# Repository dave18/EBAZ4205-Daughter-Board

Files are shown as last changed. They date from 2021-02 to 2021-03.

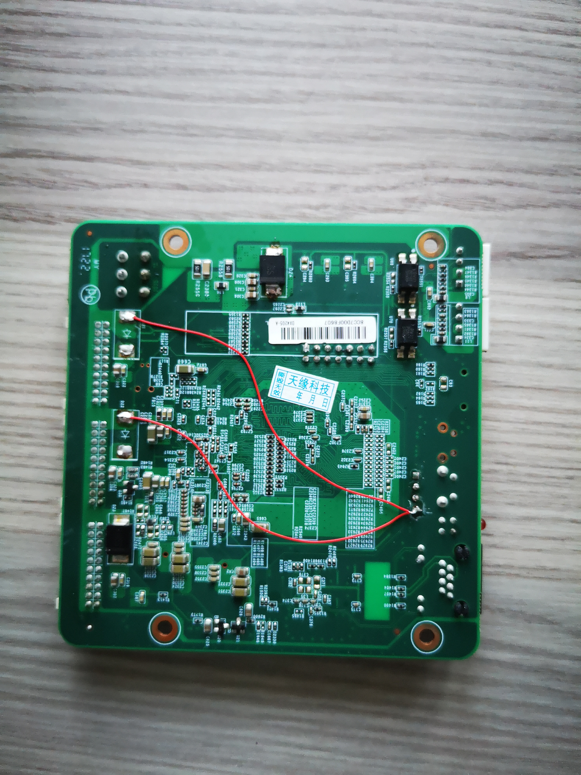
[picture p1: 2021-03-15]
EBAZ4205_Board_Bottom.jpg

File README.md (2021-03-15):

# EBAZ4205-Daughter-Board
Simple daughter board for EBAZ4205 FPGA with VGA, PS2 and standard 2.54 header

Daughter board to add VGA, SD Card Breakout and PS2 {keyboard, not playstation ;-)}  functionality to the EBAZ54205 miner board.

Also brings out IO pins to standard 2.54 header for easier interfacing.  SD Card and PS2 signal also available on pin header.

All through hole for easy assembly

Notes:

PS2 needs 5v so a 12v needs to be taken to the 12v header +connector which feeds the 5v regulator, or a separate 5v source taken directly to the 5v header.
I've adapted my EBAZ4205 board to provide 3.3V out on the VCC pins on Data 1 and Data 2.  To do this I removed the diodes at D21 and D23 and run a wire from the 3.3V VCC pin of the serial interface at J7.  There are diodes on the daughter board to avoid accidental back powering of the EBAZ4205 board.  Without this mod VGA still works but an alternative way of powering the 3.3v circuit for the SD Card and PS2 3.3v side is needed.

Design could be improved by bringing the 2mm headers neader the edge of the board but they still connect fine as they are

The 2 individual 16 pin 2.54 headers could be changed to a proper 2 x 16 pin header (they are currently spaced slightly too far apart for a 2x16 IDC connector)

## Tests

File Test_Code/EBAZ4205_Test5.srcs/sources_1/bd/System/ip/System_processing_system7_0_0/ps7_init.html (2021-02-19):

- Zynq PS Register Summary Viewer

Zynq PS7 Summary Report

User Configurations

MIO Configurations

CLK Configurations

DDR Configurations

SMC Configurations

Select Version:

Zynq Register View

MIO Registers

PLL Registers

Clock Registers

DDR Registers

Peripherals Registers

This design is targeted for xc7z010 board (part number: xc7z010clg400-1)

# Zynq Design Summary

Device | xc7z010
SpeedGrade | -1
Part | xc7z010clg400-1
Description | Zynq PS Configuration Report with register details
Vendor | Xilinx

## MIO Table View

MIO Pin | Peripheral | Signal | IO Type | Speed | Pullup | Direction
MIO 0 | NAND Flash | cs | LVCMOS 3.3V | slow | enabled | out
MIO 1
MIO 2 | NAND Flash | ale | LVCMOS 3.3V | slow | disabled | out
MIO 3 | NAND Flash | we_b | LVCMOS 3.3V | slow | disabled | out
MIO 4 | NAND Flash | data[2] | LVCMOS 3.3V | slow | disabled | inout
MIO 5 | NAND Flash | data[0] | LVCMOS 3.3V | slow | disabled | inout
MIO 6 | NAND Flash | data[1] | LVCMOS 3.3V | slow | disabled | inout
MIO 7 | NAND Flash | cle | LVCMOS 3.3V | slow | disabled | out
MIO 8 | NAND Flash | re_b | LVCMOS 3.3V | slow | disabled | out
MIO 9 | NAND Flash | data[4] | LVCMOS 3.3V | slow | enabled | inout
MIO 10 | NAND Flash | data[5] | LVCMOS 3.3V | slow | enabled | inout
MIO 11 | NAND Flash | data[6] | LVCMOS 3.3V | slow | enabled | inout
MIO 12 | NAND Flash | data[7] | LVCMOS 3.3V | slow | enabled | inout
MIO 13 | NAND Flash | data[3] | LVCMOS 3.3V | slow | enabled | inout
MIO 14 | NAND Flash | busy | LVCMOS 3.3V | slow | enabled | in
MIO 15
MIO 16
MIO 17
MIO 18
MIO 19
MIO 20
MIO 21
MIO 22
MIO 23
MIO 24 | UART 1 | tx | LVCMOS 3.3V | slow | enabled | out
MIO 25 | UART 1 | rx | LVCMOS 3.3V | slow | enabled | in
MIO 26
MIO 27
MIO 28
MIO 29
MIO 30
MIO 31
MIO 32
MIO 33
MIO 34
MIO 35
MIO 36
MIO 37
MIO 38
MIO 39
MIO 40
MIO 41
MIO 42
MIO 43
MIO 44
MIO 45
MIO 46
MIO 47
MIO 48
MIO 49
MIO 50
MIO 51
MIO 52
MIO 53

## DDR Memory information

Parameter name | Value | Description
Enable DDR | 1 | Enable DDR Controller of Zynq PS
Memory Part | MT41K128M16 JT-125
DRAM bus width | 16 Bit | Select the desired data width. Refer to the Thechnical Reference Manual(TRM) for a detailed list of supported DDR data widths
ECC | Disabled | ECC is supported only for data width of 16-bit
BURST Length (lppdr only) | 8 | Select the burst Length. It refers to the amount of data read/written after a read/write command is presented to the controller
Internal Vref | 0
Operating Frequency (MHz) | 533.333333 | Chose the clock period for the desired frequency. The allowed freq range (200 - 667 MHz) is a function of FPGA part and FPGA speed grade
HIGH temperature | Normal (0-85) | Select the operating temparature
DRAM IC bus width | 16 Bits | Provide the width of the DRAM chip
DRAM Device Capacity | 2048 MBits
Speed Bin | DDR3_1066F | Provide the Speed Bin
BANK Address Count | 3 | Defines the bank to which an active an ACTIVE, READ, WRITE, or Precharge Command is being applied
ROW Address Count | 14 | Provide the Row address for ACTIVE commands
COLUMN Address Count | 10 | Provide the Row address for READ/WRITE commands
CAS Latency | 7 | Select the Column Access Strobe (CAS) Latency. It refers to the amount of time it takes for data to appear on the pins of the memory module
CAS Write Latency | 6 | Select the CAS Write Latency
RAS to CAS Delay | 7 | Provide the row address to column address delay time. tRCD is t he time required between the memory controller asserting a row address strobe (RAS), and then asserting the column address strobe (CAS)
RECHARGE Time | 7 | Precharge Time (tRP) is the number of clock cycles needed o terminate acces s to an open row of memory, and open access to the next row
tRC (ns ) | 48.75 | Provide the Row cycle time tRC (ns)
tRASmin ( ns ) | 35.0 | tRASmin (ns) is the minimum number of clock cycles required between an Active command and issuing the Precharge command
tFAW | 40.0 | It restricts the number of activates that can be done within a certain window of time
ADDITIVE Latency | 0 | Provide the Additive Latency (ns). Increases the efficiency of the command and data bus for sustainable bandwidths
Write levelling | 1
Read gate | 1
Read gate | 1
DQS to Clock delay [0] (ns) | 0.0 | The daly difference of each DQS path delay subtracted from the clock path delay
DQS to Clock delay [1] (ns) | 0.0 | The daly difference of each DQS path delay subtracted from the clock path delay
DQS to Clock delay [2] (ns) | 0.0 | The daly difference of each DQS path delay subtracted from the clock path delay
DQS to Clock delay [3] (ns) | 0.0 | The daly difference of each DQS path delay subtracted from the clock path delay
Board delay [0] (ns) | 0.25 | The average of the data midpoint delay, of the data delays associated with a byte lane (DDR_DQ, DDR_DM) averaged with the midpoint of the cloc kdelays (DDR_CK, DR_CK_N)
Board delay [1] (ns) | 0.25 | The average of the data midpoint delay, of the data delays associated with a byte lane (DDR_DQ, DDR_DM) averaged with the midpoint of the cloc kdelays (DDR_CK, DR_CK_N)
Board delay [2] (ns) | 0.25 | The average of the data midpoint delay, of the data delays associated with a byte lane (DDR_DQ, DDR_DM) averaged with the midpoint of the cloc kdelays (DDR_CK, DR_CK_N)
Board delay [3] (ns) | 0.25 | The average of the data midpoint delay, of the data delays associated with a byte lane (DDR_DQ, DDR_DM) averaged with the midpoint of the cloc kdelays (DDR_CK, DR_CK_N)

## PS Clocks information

## PS Reference Clock : 33.333333

Peripheral | PLL source | Frequency (MHz)
CPU 6x Freq (MHz) | ARM PLL | 666.666687
SMC Freq (MHz) | IO PLL | 100.000000
UART Freq (MHz) | IO PLL | 100.000000
FPGA0 Freq (MHz) | ARM PLL | 102.564102
FPGA1 Freq (MHz) | ARM PLL | 25.157234
FPGA2 Freq (MHz) | IO PLL | 10.000000
FPGA3 Freq (MHz) | IO PLL | 10.000000

## ps7_pll_init_data_3_0

Register Name | Address | Width | Type | Reset Value | Description
SLCR_UNLOCK | 0XF8000008 | 32 | WO | 0x000000 | SLCR Write Protection Unlock
ARM_PLL_CFG | 0XF8000110 | 32 | RW | 0x000000 | ARM PLL Configuration
ARM_PLL_CTRL | 0XF8000100 | 32 | RW | 0x000000 | ARM PLL Control
ARM_PLL_CTRL | 0XF8000100 | 32 | RW | 0x000000 | ARM PLL Control
ARM_PLL_CTRL | 0XF8000100 | 32 | RW | 0x000000 | ARM PLL Control
ARM_PLL_CTRL | 0XF8000100 | 32 | RW | 0x000000 | ARM PLL Control
ARM_PLL_CTRL | 0XF8000100 | 32 | RW | 0x000000 | ARM PLL Control
ARM_CLK_CTRL | 0XF8000120 | 32 | RW | 0x000000 | CPU Clock Control
DDR_PLL_CFG | 0XF8000114 | 32 | RW | 0x000000 | DDR PLL Configuration
DDR_PLL_CTRL | 0XF8000104 | 32 | RW | 0x000000 | DDR PLL Control
DDR_PLL_CTRL | 0XF8000104 | 32 | RW | 0x000000 | DDR PLL Control
DDR_PLL_CTRL | 0XF8000104 | 32 | RW | 0x000000 | DDR PLL Control
DDR_PLL_CTRL | 0XF8000104 | 32 | RW | 0x000000 | DDR PLL Control
DDR_PLL_CTRL | 0XF8000104 | 32 | RW | 0x000000 | DDR PLL Control
DDR_CLK_CTRL | 0XF8000124 | 32 | RW | 0x000000 | DDR Clock Control
IO_PLL_CFG | 0XF8000118 | 32 | RW | 0x000000 | IO PLL Configuration
IO_PLL_CTRL | 0XF8000108 | 32 | RW | 0x000000 | IO PLL Control
IO_PLL_CTRL | 0XF8000108 | 32 | RW | 0x000000 | IO PLL Control
IO_PLL_CTRL | 0XF8000108 | 32 | RW | 0x000000 | IO PLL Control
IO_PLL_CTRL | 0XF8000108 | 32 | RW | 0x000000 | IO PLL Control
IO_PLL_CTRL | 0XF8000108 | 32 | RW | 0x000000 | IO PLL Control
SLCR_LOCK | 0XF8000004 | 32 | WO | 0x000000 | SLCR Write Protection Lock

## ps7_pll_init_data_3_0

Register Name | Address | Width | Type | Reset Value | Description

# SLCR SETTINGS

## Register ( slcr )SLCR_UNLOCK

Register Name | Address | Width | Type | Reset Value | Description
SLCR_UNLOCK | 0XF8000008 | 32 | rw | 0x00000000 | --

Field Name | Bits | Mask | Value | Shifted Value | Description
UNLOCK_KEY | 15:0 | ffff | df0d | df0d | Write the unlock key, 0xDF0D, to enable writes to the slcr registers. All slcr registers, 0xF800_0000 to 0xF800_0B74, are writeable until locked using the SLCR_LOCK register. A read of this register returns zero.
SLCR_UNLOCK@0XF8000008 | 31:0 | ffff | | df0d | SLCR Write Protection Unlock

# PLL SLCR REGISTERS

# ARM PLL INIT

## Register ( slcr )ARM_PLL_CFG

Register Name | Address | Width | Type | Reset Value | Description
ARM_PLL_CFG | 0XF8000110 | 32 | rw | 0x00000000 | --

Field Name | Bits | Mask | Value | Shifted Value | Description
PLL_RES | 7:4 | f0 | 2 | 20 | Drive the PLL_RES[3:0] input of the PLL to set the PLL loop filter resistor control
PLL_CP | 11:8 | f00 | 2 | 200 | Drive the PLL_CP[3:0] input of the PLL to set the PLL charge pump control
LOCK_CNT | 21:12 | 3ff000 | fa | fa000 | Drive the LOCK_CNT[9:0] input of the PLL to set the number of clock cycles the PLL needs to have clkref and clkfb aligned with a certain window before syaing locked.
ARM_PLL_CFG@0XF8000110 | 31:0 | 3ffff0 | | fa220 | ARM PLL Configuration

# UPDATE FB_DIV

## Register ( slcr )ARM_PLL_CTRL

Register Name | Address | Width | Type | Reset Value | Description
ARM_PLL_CTRL | 0XF8000100 | 32 | rw | 0x00000000 | --

Field Name | Bits | Mask | Value | Shifted Value | Description
PLL_FDIV | 18:12 | 7f000 | 28 | 28000 | Provide the feedback divisor for the PLL. Note: Before changing this value, the PLL must first be bypassed and then put into reset mode. Refer to the Zynq-7000 TRM, UG585, Clocks chapter for CP/RES/CNT values for the PLL.
ARM_PLL_CTRL@0XF8000100 | 31:0 | 7f000 | | 28000 | ARM PLL Control

# BY PASS PLL

## Register ( slcr )ARM_PLL_CTRL

Register Name | Address | Width | Type | Reset Value | Description
ARM_PLL_CTRL | 0XF8000100 | 32 | rw | 0x00000000 | --

Field Name | Bits | Mask | Value | Shifted Value | Description
PLL_BYPASS_FORCE | 4:4 | 10 | 1 | 10 | ARM PLL Bypass override control: PLL_BYPASS_QUAL = 0: 0: enabled, not bypassed. 1: bypassed. PLL_BYPASS_QUAL = 1 (QUAL bit default value): 0: PLL mode is set based on pin strap setting. 1: PLL bypassed regardless of the pin strapping.
ARM_PLL_CTRL@0XF8000100 | 31:0 | 10 | | 10 | ARM PLL Control

# ASSERT RESET

## Register ( slcr )ARM_PLL_CTRL

Register Name | Address | Width | Type | Reset Value | Description
ARM_PLL_CTRL | 0XF8000100 | 32 | rw | 0x00000000 | --

Field Name | Bits | Mask | Value | Shifted Value | Description
PLL_RESET | 0:0 | 1 | 1 | 1 | PLL reset control: 0: de-assert (PLL operating) 1: assert (PLL held in reset)
ARM_PLL_CTRL@0XF8000100 | 31:0 | 1 | | 1 | ARM PLL Control

# DEASSERT RESET

## Register ( slcr )ARM_PLL_CTRL

Register Name | Address | Width | Type | Reset Value | Description
ARM_PLL_CTRL | 0XF8000100 | 32 | rw | 0x00000000 | --

Field Name | Bits | Mask | Value | Shifted Value | Description
PLL_RESET | 0:0 | 1 | 0 | 0 | PLL reset control: 0: de-assert (PLL operating) 1: assert (PLL held in reset)
ARM_PLL_CTRL@0XF8000100 | 31:0 | 1 | | 0 | ARM PLL Control

# CHECK PLL STATUS

## Register ( slcr )PLL_STATUS

Register Name | Address | Width | Type | Reset Value | Description
PLL_STATUS | 0XF800010C | 32 | rw | 0x00000000 | --

Field Name | Bits | Mask | Value | Shifted Value | Description
ARM_PLL_LOCK | 0:0 | 1 | 1 | 1 | ARM PLL lock status: 0: not locked, 1: locked
PLL_STATUS@0XF800010C | 31:0 | 1 | | 1 | tobe

# REMOVE PLL BY PASS

## Register ( slcr )ARM_PLL_CTRL

Register Name | Address | Width | Type | Reset Value | Description
ARM_PLL_CTRL | 0XF8000100 | 32 | rw | 0x00000000 | --

Field Name | Bits | Mask | Value | Shifted Value | Description
PLL_BYPASS_FORCE | 4:4 | 10 | 0 | 0 | ARM PLL Bypass override control: PLL_BYPASS_QUAL = 0: 0: enabled, not bypassed. 1: bypassed. PLL_BYPASS_QUAL = 1 (QUAL bit default value): 0: PLL mode is set based on pin strap setting. 1: PLL bypassed regardless of the pin strapping.
ARM_PLL_CTRL@0XF8000100 | 31:0 | 10 | | 0 | ARM PLL Control

## Register ( slcr )ARM_CLK_CTRL

Register Name | Address | Width | Type | Reset Value | Description
ARM_CLK_CTRL | 0XF8000120 | 32 | rw | 0x00000000 | --

Field Name | Bits | Mask | Value | Shifted Value | Description
SRCSEL | 5:4 | 30 | 0 | 0 | Select the source used to generate the CPU clock: 0x: ARM PLL 10: DDR PLL 11: IO PLL This field is reset by POR only.
DIVISOR | 13:8 | 3f00 | 2 | 200 | Frequency divisor for the CPU clock source.
CPU_6OR4XCLKACT | 24:24 | 1000000 | 1 | 1000000 | CPU_6x4x Clock control: 0: disable, 1: enable
CPU_3OR2XCLKACT | 25:25 | 2000000 | 1 | 2000000 | CPU_3x2x Clock control: 0: disable, 1: enable
CPU_2XCLKACT | 26:26 | 4000000 | 1 | 4000000 | CPU_2x Clock control: 0: disable, 1: enable
CPU_1XCLKACT | 27:27 | 8000000 | 1 | 8000000 | CPU_1x Clock control: 0: disable, 1: enable
CPU_PERI_CLKACT | 28:28 | 10000000 | 1 | 10000000 | Clock active: 0: Clock is disabled 1: Clock is enabled
ARM_CLK_CTRL@0XF8000120 | 31:0 | 1f003f30 | | 1f000200 | CPU Clock Control

# DDR PLL INIT

## Register ( slcr )DDR_PLL_CFG

Register Name | Address | Width | Type | Reset Value | Description
DDR_PLL_CFG | 0XF8000114 | 32 | rw | 0x00000000 | --

Field Name | Bits | Mask | Value | Shifted Value | Description
PLL_RES | 7:4 | f0 | 2 | 20 | Drive the PLL_RES[3:0] input of the PLL to set the PLL loop filter resistor control.
PLL_CP | 11:8 | f00 | 2 | 200 | Drive the PLL_CP[3:0] input of the PLL to set the PLL charge pump control.
LOCK_CNT | 21:12 | 3ff000 | 12c | 12c000 | Drive the LOCK_CNT[9:0] input of the PLL to set the number of clock cycles the PLL needs to have clkref and clkfb aligned with a certain window before staying locked.
DDR_PLL_CFG@0XF8000114 | 31:0 | 3ffff0 | | 12c220 | DDR PLL Configuration

# UPDATE FB_DIV

## Register ( slcr )DDR_PLL_CTRL

Register Name | Address | Width | Type | Reset Value | Description
DDR_PLL_CTRL | 0XF8000104 | 32 | rw | 0x00000000 | --

Field Name | Bits | Mask | Value | Shifted Value | Description
PLL_FDIV | 18:12 | 7f000 | 20 | 20000 | Provide the feedback divisor for the PLL. Note: Before changing this value, the PLL must first be bypassed and then put into reset mode. Refer to the Zynq-7000 TRM, UG585, Clocks chapter for CP/RES/CNT values for the PLL.
DDR_PLL_CTRL@0XF8000104 | 31:0 | 7f000 | | 20000 | DDR PLL Control

# BY PASS PLL

## Register ( slcr )DDR_PLL_CTRL

Register Name | Address | Width | Type | Reset Value | Description
DDR_PLL_CTRL | 0XF8000104 | 32 | rw | 0x00000000 | --

Field Name | Bits | Mask | Value | Shifted Value | Description
PLL_BYPASS_FORCE | 4:4 | 10 | 1 | 10 | DDR PLL Bypass override control: PLL_BYPASS_QUAL = 0 0: enabled, not bypassed. 1: bypassed. PLL_BYPASS_QUAL = 1 (QUAL bit default value) 0: PLL mode is set based on pin strap setting. 1: PLL bypass is enabled regardless of the pin strapping.
DDR_PLL_CTRL@0XF8000104 | 31:0 | 10 | | 10 | DDR PLL Control

# ASSERT RESET

## Register ( slcr )DDR_PLL_CTRL

Register Name | Address | Width | Type | Reset Value | Description
DDR_PLL_CTRL | 0XF8000104 | 32 | rw | 0x00000000 | --

Field Name | Bits | Mask | Value | Shifted Value | Description
PLL_RESET | 0:0 | 1 | 1 | 1 | PLL reset control: 0: de-assert (PLL operating) 1: assert (PLL held in reset)
DDR_PLL_CTRL@0XF8000104 | 31:0 | 1 | | 1 | DDR PLL Control

# DEASSERT RESET

## Register ( slcr )DDR_PLL_CTRL

Register Name | Address | Width | Type | Reset Value | Description
DDR_PLL_CTRL | 0XF8000104 | 32 | rw | 0x00000000 | --

Field Name | Bits | Mask | Value | Shifted Value | Description
PLL_RESET | 0:0 | 1 | 0 | 0 | PLL reset control: 0: de-assert (PLL operating) 1: assert (PLL held in reset)
DDR_PLL_CTRL@0XF8000104 | 31:0 | 1 | | 0 | DDR PLL Control

# CHECK PLL STATUS

## Register ( slcr )PLL_STATUS

Register Name | Address | Width | Type | Reset Value | Description
PLL_STATUS | 0XF800010C | 32 | rw | 0x00000000 | --

Field Name | Bits | Mask | Value | Shifted Value | Description
DDR_PLL_LOCK | 1:1 | 2 | 1 | 2 | DDR PLL lock status: 0: not locked, 1: locked
PLL_STATUS@0XF800010C | 31:0 | 2 | | 2 | tobe

# REMOVE PLL BY PASS

## Register ( slcr )DDR_PLL_CTRL

Register Name | Address | Width | Type | Reset Value | Description
DDR_PLL_CTRL | 0XF8000104 | 32 | rw | 0x00000000 | --

Field Name | Bits | Mask | Value | Shifted Value | Description
PLL_BYPASS_FORCE | 4:4 | 10 | 0 | 0 | DDR PLL Bypass override control: PLL_BYPASS_QUAL = 0 0: enabled, not bypassed. 1: bypassed. PLL_BYPASS_QUAL = 1 (QUAL bit default value) 0: PLL mode is set based on pin strap setting. 1: PLL bypass is enabled regardless of the pin strapping.
DDR_PLL_CTRL@0XF8000104 | 31:0 | 10 | | 0 | DDR PLL Control

## Register ( slcr )DDR_CLK_CTRL

Register Name | Address | Width | Type | Reset Value | Description
DDR_CLK_CTRL | 0XF8000124 | 32 | rw | 0x00000000 | --

Field Name | Bits | Mask | Value | Shifted Value | Description
DDR_3XCLKACT | 0:0 | 1 | 1 | 1 | DDR_3x Clock control: 0: disable, 1: enable
DDR_2XCLKACT | 1:1 | 2 | 1 | 2 | DDR_2x Clock control: 0: disable, 1: enable
DDR_3XCLK_DIVISOR | 25:20 | 3f00000 | 2 | 200000 | Frequency divisor for the ddr_3x clock
DDR_2XCLK_DIVISOR | 31:26 | fc000000 | 3 | c000000 | Frequency divisor for the ddr_2x clock
DDR_CLK_CTRL@0XF8000124 | 31:0 | fff00003 | | c200003 | DDR Clock Control

# IO PLL INIT

## Register ( slcr )IO_PLL_CFG

Register Name | Address | Width | Type | Reset Value | Description
IO_PLL_CFG | 0XF8000118 | 32 | rw | 0x00000000 | --

Field Name | Bits | Mask | Value | Shifted Value | Description
PLL_RES | 7:4 | f0 | 4 | 40 | Drive the PLL_RES[3:0] input of the PLL to set the PLL loop filter resistor control.
PLL_CP | 11:8 | f00 | 2 | 200 | Drive the PLL_CP[3:0] input of the PLL to set the PLL charge pump control.
LOCK_CNT | 21:12 | 3ff000 | fa | fa000 | Drive the LOCK_CNT[9:0] input of the PLL to set the number of clock cycles the PLL needs to have clkref and clkfb aligned with a certain window before staying locked.
IO_PLL_CFG@0XF8000118 | 31:0 | 3ffff0 | | fa240 | IO PLL Configuration

# UPDATE FB_DIV

## Register ( slcr )IO_PLL_CTRL

Register Name | Address | Width | Type | Reset Value | Description
IO_PLL_CTRL | 0XF8000108 | 32 | rw | 0x00000000 | --

Field Name | Bits | Mask | Value | Shifted Value | Description
PLL_FDIV | 18:12 | 7f000 | 30 | 30000 | Provide the feedback divisor for the PLL. Note: Before changing this value, the PLL must first be bypassed and then put into reset mode. Refer to the Zynq-7000 TRM, UG585, Clocks chapter for CP/RES/CNT values for programming the PLL.
IO_PLL_CTRL@0XF8000108 | 31:0 | 7f000 | | 30000 | IO PLL Control

# BY PASS PLL

## Register ( slcr )IO_PLL_CTRL

Register Name | Address | Width | Type | Reset Value | Description
IO_PLL_CTRL | 0XF8000108 | 32 | rw | 0x00000000 | --

Field Name | Bits | Mask | Value | Shifted Value | Description
PLL_BYPASS_FORCE | 4:4 | 10 | 1 | 10 | IO PLL Bypass override control: PLL_BYPASS_QUAL = 0 0: enabled, not bypassed. 1: bypassed. PLL_BYPASS_QUAL = 1 (QUAL bit default value) 0: PLL mode is set based on pin strap setting. 1: PLL bypass is enabled regardless of the pin strapping.
IO_PLL_CTRL@0XF8000108 | 31:0 | 10 | | 10 | IO PLL Control

# ASSERT RESET

## Register ( slcr )IO_PLL_CTRL

Register Name | Address | Width | Type | Reset Value | Description
IO_PLL_CTRL | 0XF8000108 | 32 | rw | 0x00000000 | --

Field Name | Bits | Mask | Value | Shifted Value | Description
PLL_RESET | 0:0 | 1 | 1 | 1 | PLL Reset control: 0: de-assert (PLL operating) 1: assert (PLL held in reset)
IO_PLL_CTRL@0XF8000108 | 31:0 | 1 | | 1 | IO PLL Control

# DEASSERT RESET

## Register ( slcr )IO_PLL_CTRL

Register Name | Address | Width | Type | Reset Value | Description
IO_PLL_CTRL | 0XF8000108 | 32 | rw | 0x00000000 | --

Field Name | Bits | Mask | Value | Shifted Value | Description
PLL_RESET | 0:0 | 1 | 0 | 0 | PLL Reset control: 0: de-assert (PLL operating) 1: assert (PLL held in reset)
IO_PLL_CTRL@0XF8000108 | 31:0 | 1 | | 0 | IO PLL Control

# CHECK PLL STATUS

## Register ( slcr )PLL_STATUS

Register Name | Address | Width | Type | Reset Value | Description
PLL_STATUS | 0XF800010C | 32 | rw | 0x00000000 | --

Field Name | Bits | Mask | Value | Shifted Value | Description
IO_PLL_LOCK | 2:2 | 4 | 1 | 4 | IO PLL lock status: 0: not locked, 1: locked
PLL_STATUS@0XF800010C | 31:0 | 4 | | 4 | tobe

# REMOVE PLL BY PASS

## Register ( slcr )IO_PLL_CTRL

Register Name | Address | Width | Type | Reset Value | Description
IO_PLL_CTRL | 0XF8000108 | 32 | rw | 0x00000000 | --

Field Name | Bits | Mask | Value | Shifted Value | Description
PLL_BYPASS_FORCE | 4:4 | 10 | 0 | 0 | IO PLL Bypass override control: PLL_BYPASS_QUAL = 0 0: enabled, not bypassed. 1: bypassed. PLL_BYPASS_QUAL = 1 (QUAL bit default value) 0: PLL mode is set based on pin strap setting. 1: PLL bypass is enabled regardless of the pin strapping.
IO_PLL_CTRL@0XF8000108 | 31:0 | 10 | | 0 | IO PLL Control

# LOCK IT BACK

## Register ( slcr )SLCR_LOCK

Register Name | Address | Width | Type | Reset Value | Description
SLCR_LOCK | 0XF8000004 | 32 | rw | 0x00000000 | --

Field Name | Bits | Mask | Value | Shifted Value | Description
LOCK_KEY | 15:0 | ffff | 767b | 767b | Write the lock key, 0x767B, to write protect the slcr registers: all slcr registers, 0xF800_0000 to 0xF800_0B74, are write protected until the unlock key is written to the SLCR_UNLOCK register. A read of this register returns zero.
SLCR_LOCK@0XF8000004 | 31:0 | ffff | | 767b | SLCR Write Protection Lock

## ps7_clock_init_data_3_0

Register Name | Address | Width | Type | Reset Value | Description
SLCR_UNLOCK | 0XF8000008 | 32 | WO | 0x000000 | SLCR Write Protection Unlock
DCI_CLK_CTRL | 0XF8000128 | 32 | RW | 0x000000 | DCI clock control
SMC_CLK_CTRL | 0XF8000148 | 32 | RW | 0x000000 | SMC Ref Clock Control
UART_CLK_CTRL | 0XF8000154 | 32 | RW | 0x000000 | UART Ref Clock Control
PCAP_CLK_CTRL | 0XF8000168 | 32 | RW | 0x000000 | PCAP Clock Control
FPGA0_CLK_CTRL | 0XF8000170 | 32 | RW | 0x000000 | PL Clock 0 Output control
FPGA1_CLK_CTRL | 0XF8000180 | 32 | RW | 0x000000 | PL Clock 1 Output control
CLK_621_TRUE | 0XF80001C4 | 32 | RW | 0x000000 | CPU Clock Ratio Mode select
APER_CLK_CTRL | 0XF800012C | 32 | RW | 0x000000 | AMBA Peripheral Clock Control
SLCR_LOCK | 0XF8000004 | 32 | WO | 0x000000 | SLCR Write Protection Lock

## ps7_clock_init_data_3_0

Register Name | Address | Width | Type | Reset Value | Description

# SLCR SETTINGS

## Register ( slcr )SLCR_UNLOCK

Register Name | Address | Width | Type | Reset Value | Description
SLCR_UNLOCK | 0XF8000008 | 32 | rw | 0x00000000 | --

Field Name | Bits | Mask | Value | Shifted Value | Description
UNLOCK_KEY | 15:0 | ffff | df0d | df0d | Write the unlock key, 0xDF0D, to enable writes to the slcr registers. All slcr registers, 0xF800_0000 to 0xF800_0B74, are writeable until locked using the SLCR_LOCK register. A read of this register returns zero.
SLCR_UNLOCK@0XF8000008 | 31:0 | ffff | | df0d | SLCR Write Protection Unlock

# CLOCK CONTROL SLCR REGISTERS

## Register ( slcr )DCI_CLK_CTRL

Register Name | Address | Width | Type | Reset Value | Description
DCI_CLK_CTRL | 0XF8000128 | 32 | rw | 0x00000000 | --

Field Name | Bits | Mask | Value | Shifted Value | Description
CLKACT | 0:0 | 1 | 1 | 1 | DCI clock control - 0: disable, 1: enable
DIVISOR0 | 13:8 | 3f00 | f | f00 | Provides the divisor used to divide the source clock to generate the required generated clock frequency.
DIVISOR1 | 25:20 | 3f00000 | 7 | 700000 | Provides the divisor used to divide the source clock to generate the required generated clock frequency. Second cascade divider
DCI_CLK_CTRL@0XF8000128 | 31:0 | 3f03f01 | | 700f01 | DCI clock control

## Register ( slcr )SMC_CLK_CTRL

Register Name | Address | Width | Type | Reset Value | Description
SMC_CLK_CTRL | 0XF8000148 | 32 | rw | 0x00000000 | --

Field Name | Bits | Mask | Value | Shifted Value | Description
CLKACT | 0:0 | 1 | 1 | 1 | SMC Reference Clock control 0: disable, 1: enable
SRCSEL | 5:4 | 30 | 0 | 0 | Select clock source generate SMC clock: 0x: IO PLL, 10: ARM PLL, 11: DDR PLL
DIVISOR | 13:8 | 3f00 | 10 | 1000 | Divisor for SMC source clock.
SMC_CLK_CTRL@0XF8000148 | 31:0 | 3f31 | | 1001 | SMC Ref Clock Control
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

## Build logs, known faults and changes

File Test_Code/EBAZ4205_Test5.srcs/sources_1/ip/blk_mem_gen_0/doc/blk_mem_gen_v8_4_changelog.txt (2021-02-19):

2019.1.3:
 * Version 8.4 (Rev. 3)
 * No changes

2019.1.2:
 * Version 8.4 (Rev. 3)
 * No changes

2019.1.1:
 * Version 8.4 (Rev. 3)
 * No changes

2019.1:
 * Version 8.4 (Rev. 3)
 * General: Internal device family change, no functional changes

2018.3.1:
 * Version 8.4 (Rev. 2)
 * No changes

2018.3:
 * Version 8.4 (Rev. 2)
 * Feature Enhancement: Read Latency Support added for URAM when selected through IP Integrator
 * Other: Power Calculations disabled for URAM primitives in IP GUI, no functional changes
 * Other: Internal device family change, no functional changes

2018.2:
 * Version 8.4 (Rev. 1)
 * No changes

2018.1:
 * Version 8.4 (Rev. 1)
 * No changes

2017.4:
 * Version 8.4 (Rev. 1)
 * General: Write depth shown in IP GUI is now dependent on number of BRAMs available in a chosen device, no functional changes

2017.3:
 * Version 8.4
 * General: Safety Circuit option is enabled by default if reset option in any one port is enabled

2017.2:
 * Version 8.3 (Rev. 6)
 * No changes

2017.1:
 * Version 8.3 (Rev. 6)
 * General: Internal device family change, no functional changes
 * General: When common_clock is selected clkb is internally connected to clka, but the interface remains same to support the backword compatiability. User make sure of connecting the both the clocks to same clock source when in common_clock mode

2016.4:
 * Version 8.3 (Rev. 5)
 * General: Fixes for behavioral Model issues when built-IN ECC is enabled (to be consistent with RTL)

2016.3:
 * Version 8.3 (Rev. 4)
 * Feature Enhancement: URAM addressing updates while calling XPM_Memory when 32-bit addressing is enabled
 * Other: Enable support for future devices
 * Other: Source HDL files are concatenated into a single file to speed up synthesis and simulation. No changes required by the user

2016.2:
 * Version 8.3 (Rev. 3)
 * updated the IP,not to set WRITE_DEPTH parameter to 8192 everytime when the mode is switched to BRAM_Controller
 * Updated the IP to support the device package changes

2016.1:
 * Version 8.3 (Rev. 2)
 * Updated the IP to deliver only verilog behavioral model
 * Updated the IP to support UltraRAM in IP Integrator
 * Updated the IP to support the device package changes

2015.4.2:
 * Version 8.3 (Rev. 1)
 * No changes

2015.4.1:
 * Version 8.3 (Rev. 1)
 * No changes

2015.4:
 * Version 8.3 (Rev. 1)
 * Updated the IP to support the device package changes

2015.3:
 * Version 8.3
 * IP revision number added to HDL module, library, and include file names, to support designs with both locked and upgraded IP instances
 * New ports rsta_busy and rstb_busy are added to enable the safety circuitry to minimize the occurrence of BRAM data corruption
 * Simulation models are delivered in VHDL only

2015.2.1:
 * Version 8.2 (Rev. 5)
 * No changes

2015.2:
 * Version 8.2 (Rev. 5)
 * No changes

2015.1:
 * Version 8.2 (Rev. 5)
 * Delivering non encrypted behavioral models
 * Supported memory depth is increased up to 1M words
 * Added the power saving feature (RDADDRCHG) for ultrascale devices
 * Supported devices and production status are now determined automatically, to simplify support for future devices

2014.4.1:
 * Version 8.2 (Rev. 4)
 * Updated the IP to support the device package changes

2014.4:
 * Version 8.2 (Rev. 3)
 * Encrypted source files are concatenated together to reduce the number of files and to reduce simulator compile time
 * Added support for 7-series Automotive (XA) and Defense Grade (XQ) devices
 * Internal device family change, no functional changes

2014.3:
 * Version 8.2 (Rev. 2)
 * Fixed the Memory Resource Doubling issue in Simple Dual Port RAM when aspect ratio is used
 * Fixed the GUI crash in Simple Dual Port RAM
 * Added support of all write modes in Simple Dual Port RAM when ECC is not used
 * Increased the supported depth to a maximum value of 256k

2014.2:
 * Version 8.2 (Rev. 1)
 * Updated the GUI tool tip for Byte write enable in the page-1 of block memory generator GUI

2014.1:
 * Version 8.2
 * Added support of the cascaded Primitives of widths 1 and 2 for ultra-scale devices
 * Added support of the ECCPIPE register in the built-in ecc mode for ultra-scale devices
 * Added support of the dynamic power saving for ultra-scale devices
 * Improved timing efficiency in the IP Integrator by minimizing the use of output mux for the 7-series devices
 * Internal device family name change, no functional changes

2013.4:
 * Version 8.1
 * The Primitive output registers are made "ON" by default in the stand alone mode
 * Added cascaded support for ultrascale devices to construct 64Kx1 primitive by using two 32Kx1 primitives
 * Added support for ultrascale devices

2013.3:
 * Version 8.0 (Rev. 2)
 * Added parameter "CTRL_ECC_ALGO" for supporting ECC in  IP Integrator.
 * Improved GUI speed and responsivness, no functional changes
 * Reduced synthesis and simulation warnings
 * Added support for Cadence IES and Synopsys VCS simulators
 * Changed the default option of ENABLE PORT TYPE to "USE_ENA_PIN"
 * Changed BRAM Interface DIN and DOUT to match bus interface directions.

2013.2:
 * Version 8.0 (Rev. 1)
 * No Changes

2013.1:
 * Version 8.0
 * Native Vivado Release
 * There have been no functional or interface changes to this IP.  The version number has changed to support unique versioning in Vivado starting with 2013.1.

(c) Copyright 2002 - 2019 Xilinx, Inc. All rights reserved.

This file contains confidential and proprietary information
of Xilinx, Inc. and is protected under U.S. and
international copyright and other intellectual property
laws.

DISCLAIMER
This disclaimer is not a license and does not grant any
rights to the materials distributed herewith. Except as
otherwise provided in a valid license issued to you by
Xilinx, and to the maximum extent permitted by applicable
law: (1) THESE MATERIALS ARE MADE AVAILABLE "AS IS" AND
WITH ALL FAULTS, AND XILINX HEREBY DISCLAIMS ALL WARRANTIES
AND CONDITIONS, EXPRESS, IMPLIED, OR STATUTORY, INCLUDING
BUT NOT LIMITED TO WARRANTIES OF MERCHANTABILITY, NON-
INFRINGEMENT, OR FITNESS FOR ANY PARTICULAR PURPOSE; and
(2) Xilinx shall not be liable (whether in contract or tort,
including negligence, or under any other theory of
liability) for any loss or damage of any kind or nature
related to, arising under or in connection with these
materials, including for any direct, or any indirect,
special, incidental, or consequential loss or damage
(including loss of data, profits, goodwill, or any type of
loss or damage suffered as a result of any action brought
by a third party) even if such damage or loss was
reasonably foreseeable or Xilinx had been advised of the
possibility of the same.

CRITICAL APPLICATIONS
Xilinx products are not designed or intended to be fail-
safe, or for use in any application requiring fail-safe
performance, such as life-support or safety devices or
systems, Class III medical devices, nuclear facilities,
applications related to the deployment of airbags, or any
other applications that could lead to death, personal
injury, or severe property or environmental damage
(individually and collectively, "Critical
Applications"). Customer assumes the sole risk and
liability of any use of Xilinx products in Critical
Applications, subject only to applicable laws and
regulations governing limitations on product liability.

THIS COPYRIGHT NOTICE AND DISCLAIMER MUST BE RETAINED AS
PART OF THIS FILE AT ALL TIMES.

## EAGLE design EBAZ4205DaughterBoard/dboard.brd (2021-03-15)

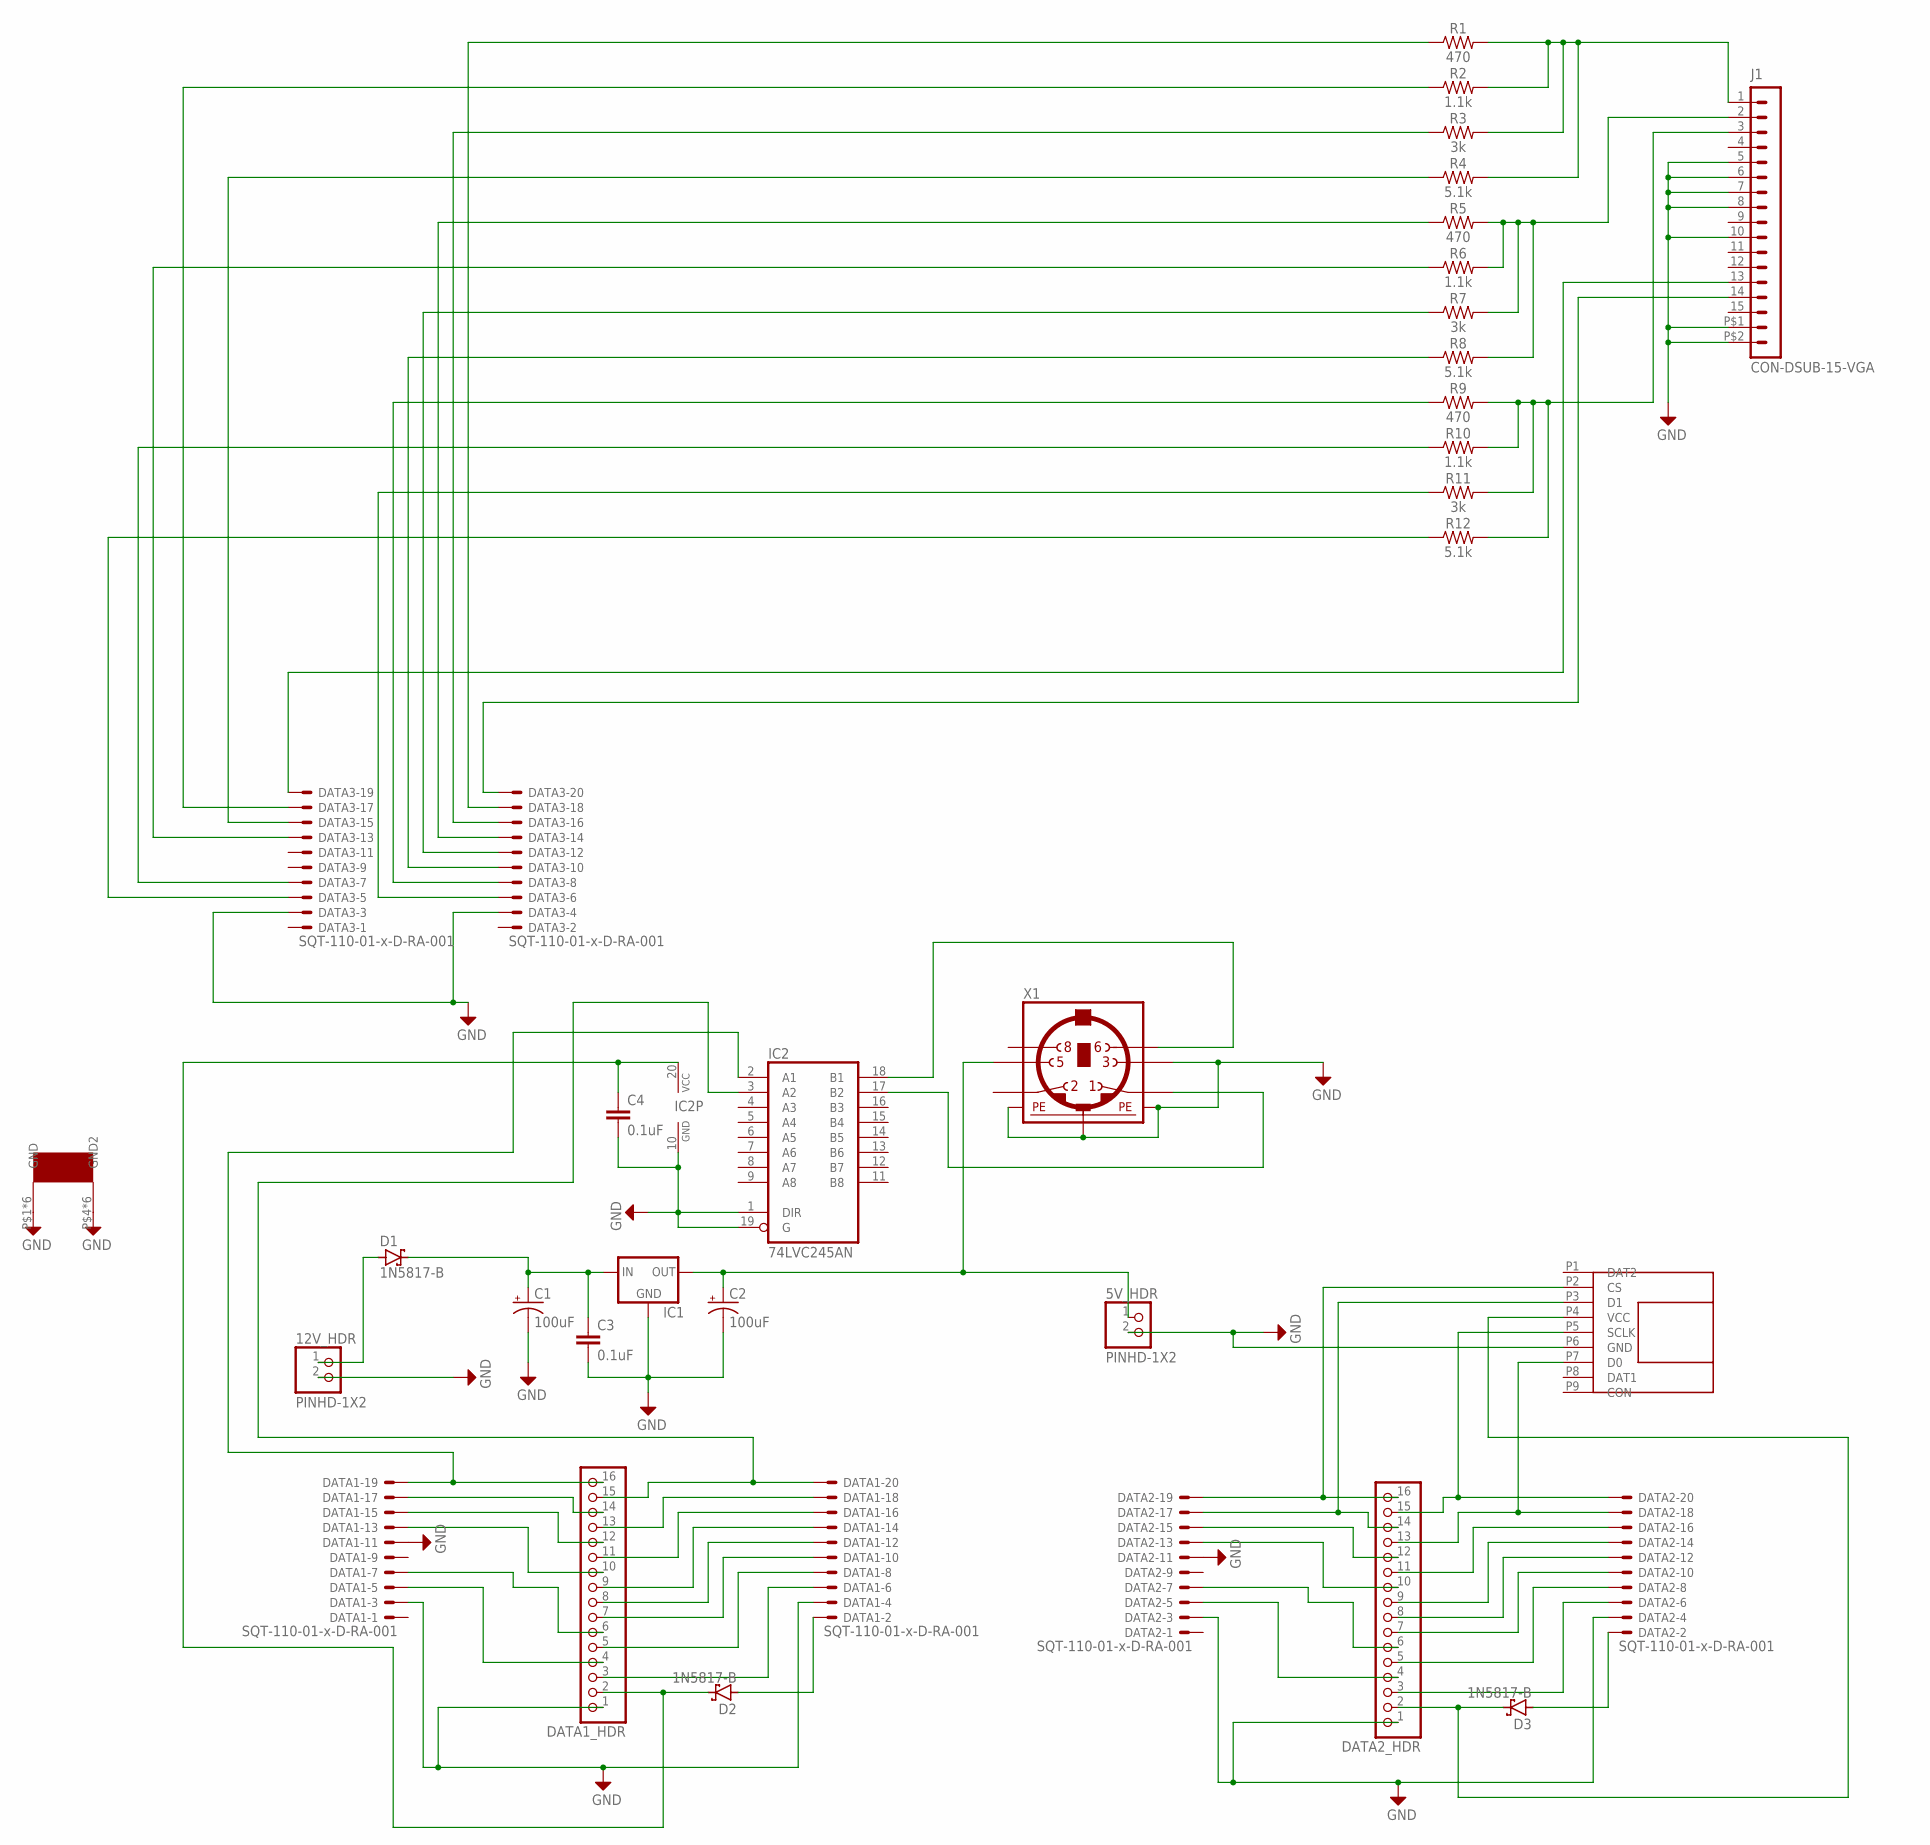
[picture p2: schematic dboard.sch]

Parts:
5V_HDR, 12V_HDR: PINHD-1X2; 1X02
C1, C2: 100uF; CPOL-RADIAL-2.5MM-6.5MM
C3, C4: 0.1uF; CAP-PTH-SMALL-KIT
D1, D2, D3: 1N5817-B; DO41-7.6
DATA1, DATA2, DATA3: SQT-110-01-x-D-RA-001; 332-20
DATA1_HDR, DATA2_HDR: PINHD-1X16; 1X16
IC1: 78XXL
IC2: 74LVC245AN; DIL20
J1: CON-DSUB-15-VGA; 181-015-212-171
R1, R5, R9: 470; AXIAL-0.3
R2, R6, R10: 1.1k; AXIAL-0.3
R3, R7, R11: 3k; AXIAL-0.3
R4, R8, R12: 5.1k; AXIAL-0.3
U$1: 7085THERMALPAD; 7805THERMALPAD
U$2: TF_CARD_BREAKOUT; OPEN-SMARTTFCARDBREAKOUT
X1: MINI_DIN_6; M_DIN6

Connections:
A20: DATA1.6, DATA1_HDR.3
B19: DATA1.8, DATA1_HDR.5
B20: DATA1.7, DATA1_HDR.6
C20: DATA1.10, DATA1_HDR.7
D18: DATA1.13, DATA1_HDR.10
D19: DATA1.15, DATA1_HDR.12
D20: DATA1.14, DATA1_HDR.9
DATA1_33V: D2.A, DATA1.2
DATA2_33V: D3.A, DATA2.2
E19: DATA1.17, DATA1_HDR.14
F19: DATA1.20, DATA1_HDR.15, IC2.3 (A2)
F20: DATA1.18, DATA1_HDR.13
G19: DATA2.8, DATA2_HDR.5
G20: DATA2.6, DATA2_HDR.3
GND: 5V_HDR.2, 12V_HDR.2, C1.2 (-), C2.2 (-), C3.2, C4.2, DATA1.3, DATA1.4, DATA1.11, DATA1_HDR.1, DATA2.3, DATA2.4, DATA2.11, DATA2_HDR.1, DATA3.3, DATA3.4, IC1.GND, IC2.1 (DIR), IC2.10 (GND), IC2.19 (G), J1.5, J1.6, J1.7, J1.8, J1.10, J1.P$1 (16), J1.P$2 (17), U$1.P$1 (GND), U$1.P$4 (GND2), U$1.P$6 (GND), U$1.P$7 (GND), U$1.P$8 (GND), U$1.P$9 (GND), U$1.P$10 (GND), U$1.P$11 (GND2), U$1.P$14 (GND2), U$1.P$19 (GND2), U$1.P$21 (GND2), U$1.P$24 (GND2), U$2.P6 (GND), X1.3, X1.SH1 (PE1), X1.SH2 (PE2), X1.SH3 (PE3)
H16: DATA1.5, DATA1_HDR.4
H17: DATA1.12, DATA1_HDR.8
H18: DATA1.16, DATA1_HDR.11
H20: DATA2.7, DATA2_HDR.6
HSYNC: DATA3.19, J1.13
J18: DATA2.5, DATA2_HDR.4
J19: DATA2.10, DATA2_HDR.7
J20: DATA2.13, DATA2_HDR.10
K17: DATA1.19, DATA1_HDR.16, IC2.2 (A1)
K18: DATA2.12, DATA2_HDR.8
K19: DATA2.14, DATA2_HDR.9
KBD_VCC: C4.1, D2.C, DATA1_HDR.2, IC2.20 (VCC)
L16: DATA2.16, DATA2_HDR.11
L19: DATA2.15, DATA2_HDR.12
unnamed: C1.1 (+), C3.1, D1.C, IC1.IN
PS2_CLK: IC2.18 (B1), X1.6
PS2_DATA: IC2.17 (B2), X1.1
SD_CS: DATA2.19, DATA2_HDR.16, U$2.P2 (CS)
SD_MISO: DATA2.18, DATA2_HDR.13, U$2.P7 (D0)
SD_MOSI: DATA2.17, DATA2_HDR.14, U$2.P3 (D1)
SD_SCLK: DATA2.20, DATA2_HDR.15, U$2.P5 (SCLK)
SD_VCC: D3.C, DATA2_HDR.2, U$2.P4 (VCC)
VCC+5V: 5V_HDR.1, C2.1 (+), IC1.OUT, X1.5
VGA_B0: DATA3.5, R12.P$1 (1)
VGA_B1: DATA3.6, R11.P$1 (1)
VGA_B2: DATA3.7, R10.P$1 (1)
VGA_B3: DATA3.8, R9.P$1 (1)
VGA_BLUE: J1.3, R9.P$2 (2), R10.P$2 (2), R11.P$2 (2), R12.P$2 (2)
VGA_G0: DATA3.10, R8.P$1 (1)
VGA_G1: DATA3.12, R7.P$1 (1)
VGA_G2: DATA3.13, R6.P$1 (1)
VGA_G3: DATA3.14, R5.P$1 (1)
VGA_GREEN: J1.2, R5.P$2 (2), R6.P$2 (2), R7.P$2 (2), R8.P$2 (2)
VGA_R0: DATA3.15, R4.P$1 (1)
VGA_R1: DATA3.16, R3.P$1 (1)
VGA_R2: DATA3.17, R2.P$1 (1)
VGA_R3: DATA3.18, R1.P$1 (1)
VGA_RED: J1.1, R1.P$2 (2), R2.P$2 (2), R3.P$2 (2), R4.P$2 (2)
VIN_12V: 12V_HDR.1, D1.A
VSYNC: DATA3.20, J1.14

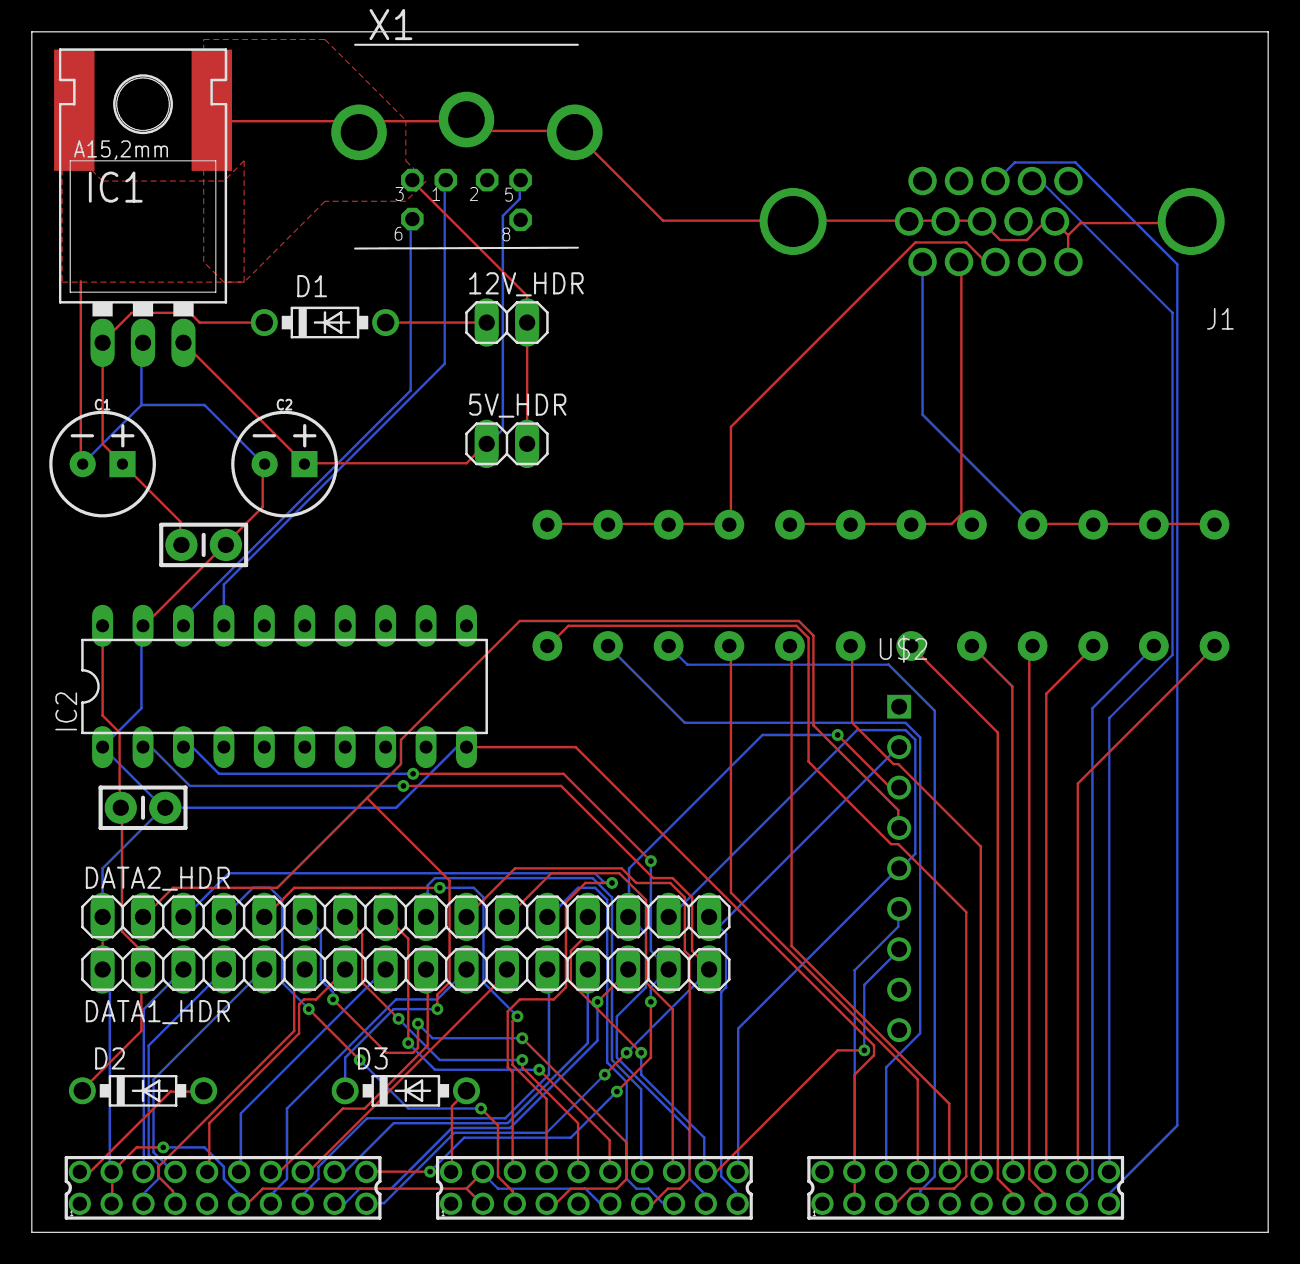
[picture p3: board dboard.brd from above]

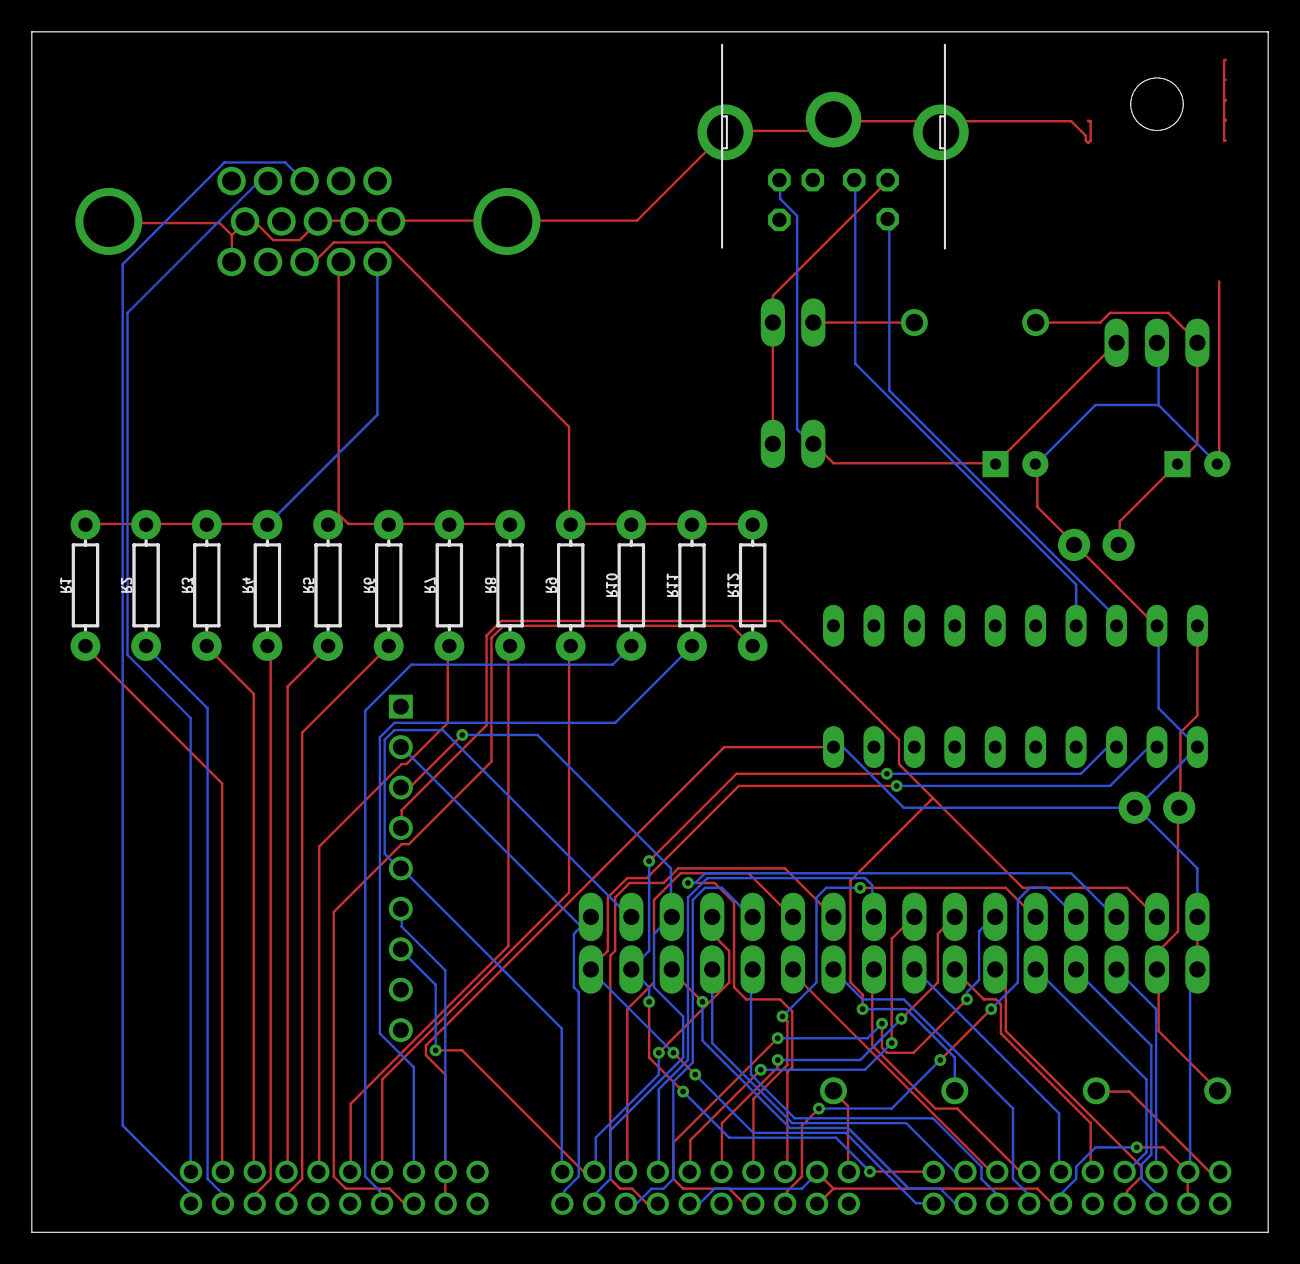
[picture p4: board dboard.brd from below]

Board: 2 copper layers, 77.7 x 75.4 mm, 32 parts (12 on the bottom side), 55 nets.

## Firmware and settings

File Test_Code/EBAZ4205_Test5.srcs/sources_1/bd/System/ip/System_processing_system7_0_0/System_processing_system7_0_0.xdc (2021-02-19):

############################################################################
##
##  Xilinx, Inc. 2006            www.xilinx.com
############################################################################
##  File name :       ps7_constraints.xdc
##
##  Details :     Constraints file
##                    FPGA family:       zynq
##                    FPGA:              xc7z010clg400-1
##                    Device Size:        xc7z010
##                    Package:            clg400
##                    Speedgrade:         -1
##
##
############################################################################
############################################################################
############################################################################
# Clock constraints                                                        #
############################################################################
create_clock -name clk_fpga_0 -period "9.75" [get_pins "PS7_i/FCLKCLK[0]"]
set_input_jitter clk_fpga_0 0.2925
#The clocks are asynchronous, user should constrain them appropriately.#
create_clock -name clk_fpga_1 -period "39.749" [get_pins "PS7_i/FCLKCLK[1]"]
set_input_jitter clk_fpga_1 1.19247
#The clocks are asynchronous, user should constrain them appropriately.#


############################################################################
# I/O STANDARDS and Location Constraints                                   #
############################################################################

#  UART 1 / rx / MIO[25]
set_property iostandard "LVCMOS33" [get_ports "MIO[25]"]
set_property PACKAGE_PIN "F15" [get_ports "MIO[25]"]
set_property slew "slow" [get_ports "MIO[25]"]
set_property drive "8" [get_ports "MIO[25]"]
set_property pullup "TRUE" [get_ports "MIO[25]"]
set_property PIO_DIRECTION "INPUT" [get_ports "MIO[25]"]
#  UART 1 / tx / MIO[24]
set_property iostandard "LVCMOS33" [get_ports "MIO[24]"]
set_property PACKAGE_PIN "A16" [get_ports "MIO[24]"]
set_property slew "slow" [get_ports "MIO[24]"]
set_property drive "8" [get_ports "MIO[24]"]
set_property pullup "TRUE" [get_ports "MIO[24]"]
set_property PIO_DIRECTION "OUTPUT" [get_ports "MIO[24]"]
#  NAND Flash / busy / MIO[14]
set_property iostandard "LVCMOS33" [get_ports "MIO[14]"]
set_property PACKAGE_PIN "C5" [get_ports "MIO[14]"]
set_property slew "slow" [get_ports "MIO[14]"]
set_property drive "8" [get_ports "MIO[14]"]
set_property pullup "TRUE" [get_ports "MIO[14]"]
set_property PIO_DIRECTION "INPUT" [get_ports "MIO[14]"]
#  NAND Flash / data[3] / MIO[13]
set_property iostandard "LVCMOS33" [get_ports "MIO[13]"]
set_property PACKAGE_PIN "E8" [get_ports "MIO[13]"]
set_property slew "slow" [get_ports "MIO[13]"]
set_property drive "8" [get_ports "MIO[13]"]
set_property pullup "TRUE" [get_ports "MIO[13]"]
set_property PIO_DIRECTION "BIDIR" [get_ports "MIO[13]"]
#  NAND Flash / data[7] / MIO[12]
set_property iostandard "LVCMOS33" [get_ports "MIO[12]"]
set_property PACKAGE_PIN "D9" [get_ports "MIO[12]"]
set_property slew "slow" [get_ports "MIO[12]"]
set_property drive "8" [get_ports "MIO[12]"]
set_property pullup "TRUE" [get_ports "MIO[12]"]
set_property PIO_DIRECTION "BIDIR" [get_ports "MIO[12]"]
#  NAND Flash / data[6] / MIO[11]
set_property iostandard "LVCMOS33" [get_ports "MIO[11]"]
set_property PACKAGE_PIN "C6" [get_ports "MIO[11]"]
set_property slew "slow" [get_ports "MIO[11]"]
set_property drive "8" [get_ports "MIO[11]"]
set_property pullup "TRUE" [get_ports "MIO[11]"]
set_property PIO_DIRECTION "BIDIR" [get_ports "MIO[11]"]
#  NAND Flash / data[5] / MIO[10]
set_property iostandard "LVCMOS33" [get_ports "MIO[10]"]
set_property PACKAGE_PIN "E9" [get_ports "MIO[10]"]
set_property slew "slow" [get_ports "MIO[10]"]
set_property drive "8" [get_ports "MIO[10]"]
set_property pullup "TRUE" [get_ports "MIO[10]"]
set_property PIO_DIRECTION "BIDIR" [get_ports "MIO[10]"]
#  NAND Flash / data[4] / MIO[9]
set_property iostandard "LVCMOS33" [get_ports "MIO[9]"]
set_property PACKAGE_PIN "B5" [get_ports "MIO[9]"]
set_property slew "slow" [get_ports "MIO[9]"]
set_property drive "8" [get_ports "MIO[9]"]
set_property pullup "TRUE" [get_ports "MIO[9]"]
set_property PIO_DIRECTION "BIDIR" [get_ports "MIO[9]"]
#  NAND Flash / re_b / MIO[8]
set_property iostandard "LVCMOS33" [get_ports "MIO[8]"]
set_property PACKAGE_PIN "D5" [get_ports "MIO[8]"]
set_property slew "slow" [get_ports "MIO[8]"]
set_property drive "8" [get_ports "MIO[8]"]
set_property PIO_DIRECTION "OUTPUT" [get_ports "MIO[8]"]
#  NAND Flash / cle / MIO[7]
set_property iostandard "LVCMOS33" [get_ports "MIO[7]"]
set_property PACKAGE_PIN "D8" [get_ports "MIO[7]"]
set_property slew "slow" [get_ports "MIO[7]"]
set_property drive "8" [get_ports "MIO[7]"]
set_property PIO_DIRECTION "OUTPUT" [get_ports "MIO[7]"]
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

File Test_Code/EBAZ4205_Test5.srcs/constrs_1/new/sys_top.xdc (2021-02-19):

#set_property PACKAGE_PIN F19 [get_ports sys_clk]
#set_property IOSTANDARD LVCMOS33 [get_ports sys_clk]

#set_property PACKAGE_PIN M20 [get_ports sys_clk]
#set_property IOSTANDARD LVCMOS33 [get_ports sys_clk]

#set_property PACKAGE_PIN L17 [get_ports pix_clk]
#set_property IOSTANDARD LVCMOS33 [get_ports pix_clk]

#set_property PACKAGE_PIN F19 [get_ports h_sync]
#set_property IOSTANDARD LVCMOS33 [get_ports h_sync]
#set_property PACKAGE_PIN K17 [get_ports v_sync]
#set_property IOSTANDARD LVCMOS33 [get_ports v_sync]

#set_property PACKAGE_PIN F20 [get_ports rgb_r0]
#set_property IOSTANDARD LVCMOS33 [get_ports rgb_r0]
#set_property PACKAGE_PIN E19 [get_ports rgb_r1]
#set_property IOSTANDARD LVCMOS33 [get_ports rgb_r1]
#set_property PACKAGE_PIN H18 [get_ports rgb_r2]
#set_property IOSTANDARD LVCMOS33 [get_ports rgb_r2]
#set_property PACKAGE_PIN D19 [get_ports rgb_r3]
#set_property IOSTANDARD LVCMOS33 [get_ports rgb_r3]

#set_property PACKAGE_PIN D20 [get_ports rgb_g0]
#set_property IOSTANDARD LVCMOS33 [get_ports rgb_g0]
#set_property PACKAGE_PIN D18 [get_ports rgb_g1]
#set_property IOSTANDARD LVCMOS33 [get_ports rgb_g1]
#set_property PACKAGE_PIN H17 [get_ports rgb_g2]
#set_property IOSTANDARD LVCMOS33 [get_ports rgb_g2]
#set_property PACKAGE_PIN C20 [get_ports rgb_g3]
#set_property IOSTANDARD LVCMOS33 [get_ports rgb_g3]

#set_property PACKAGE_PIN B19 [get_ports rgb_b0]
#set_property IOSTANDARD LVCMOS33 [get_ports rgb_b0]
#set_property PACKAGE_PIN B20 [get_ports rgb_b1]
#set_property IOSTANDARD LVCMOS33 [get_ports rgb_b1]
#set_property PACKAGE_PIN A20 [get_ports rgb_b2]
#set_property IOSTANDARD LVCMOS33 [get_ports rgb_b2]
#set_property PACKAGE_PIN H16 [get_ports rgb_b3]
#set_property IOSTANDARD LVCMOS33 [get_ports rgb_b3]

set_property PACKAGE_PIN U19 [get_ports h_sync]
set_property IOSTANDARD LVCMOS33 [get_ports h_sync]
set_property PACKAGE_PIN V20 [get_ports v_sync]
set_property IOSTANDARD LVCMOS33 [get_ports v_sync]

set_property PACKAGE_PIN U20 [get_ports rgb_r0]
set_property IOSTANDARD LVCMOS33 [get_ports rgb_r0]
set_property PACKAGE_PIN T19 [get_ports rgb_r1]
set_property IOSTANDARD LVCMOS33 [get_ports rgb_r1]
set_property PACKAGE_PIN P19 [get_ports rgb_r2]
set_property IOSTANDARD LVCMOS33 [get_ports rgb_r2]
set_property PACKAGE_PIN T20 [get_ports rgb_r3]
set_property IOSTANDARD LVCMOS33 [get_ports rgb_r3]

set_property PACKAGE_PIN R18 [get_ports rgb_g0]
set_property IOSTANDARD LVCMOS33 [get_ports rgb_g0]
set_property PACKAGE_PIN R19 [get_ports rgb_g1]
set_property IOSTANDARD LVCMOS33 [get_ports rgb_g1]
set_property PACKAGE_PIN P20 [get_ports rgb_g2]
set_property IOSTANDARD LVCMOS33 [get_ports rgb_g2]
set_property PACKAGE_PIN N17 [get_ports rgb_g3]
set_property IOSTANDARD LVCMOS33 [get_ports rgb_g3]

set_property PACKAGE_PIN P18 [get_ports rgb_b0]
set_property IOSTANDARD LVCMOS33 [get_ports rgb_b0]
set_property PACKAGE_PIN M17 [get_ports rgb_b1]
set_property IOSTANDARD LVCMOS33 [get_ports rgb_b1]
set_property PACKAGE_PIN M19 [get_ports rgb_b2]
set_property IOSTANDARD LVCMOS33 [get_ports rgb_b2]
set_property PACKAGE_PIN N20 [get_ports rgb_b3]
set_property IOSTANDARD LVCMOS33 [get_ports rgb_b3]

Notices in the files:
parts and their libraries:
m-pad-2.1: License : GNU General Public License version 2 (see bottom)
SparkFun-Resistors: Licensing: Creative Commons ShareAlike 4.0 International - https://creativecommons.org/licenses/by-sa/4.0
